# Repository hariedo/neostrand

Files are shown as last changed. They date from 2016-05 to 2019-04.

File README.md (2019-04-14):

# neostrand
NeoPixel + Arduino + Vocaloid Hairband Strand Project

On YouTube:  https://youtu.be/9ahXiw0cFx8

This is a nice multi-discipline maker project combining:

* some 3D-printed parts for a hairband and a light controller case
* some Arduino Pro Mini boards, perfboard assembly style,
* some code that goes in the Arduino Atmel 328, and
* some very long strands of NeoPixel (WS2812B) RGB LEDs.

The goal is a hairband that can be worn to a Vocaloid event;
the Vocaloids are Japanese animated characters with synthesized
vocal tracks and visuals.  The lights on the hairband match the
colors and rhythm that the wearer chooses to select at any time.

Note that Vocaloid(tm) is a trademark of Yamaha Corporation, and
this project has no proprietary content nor connection with Yamaha.

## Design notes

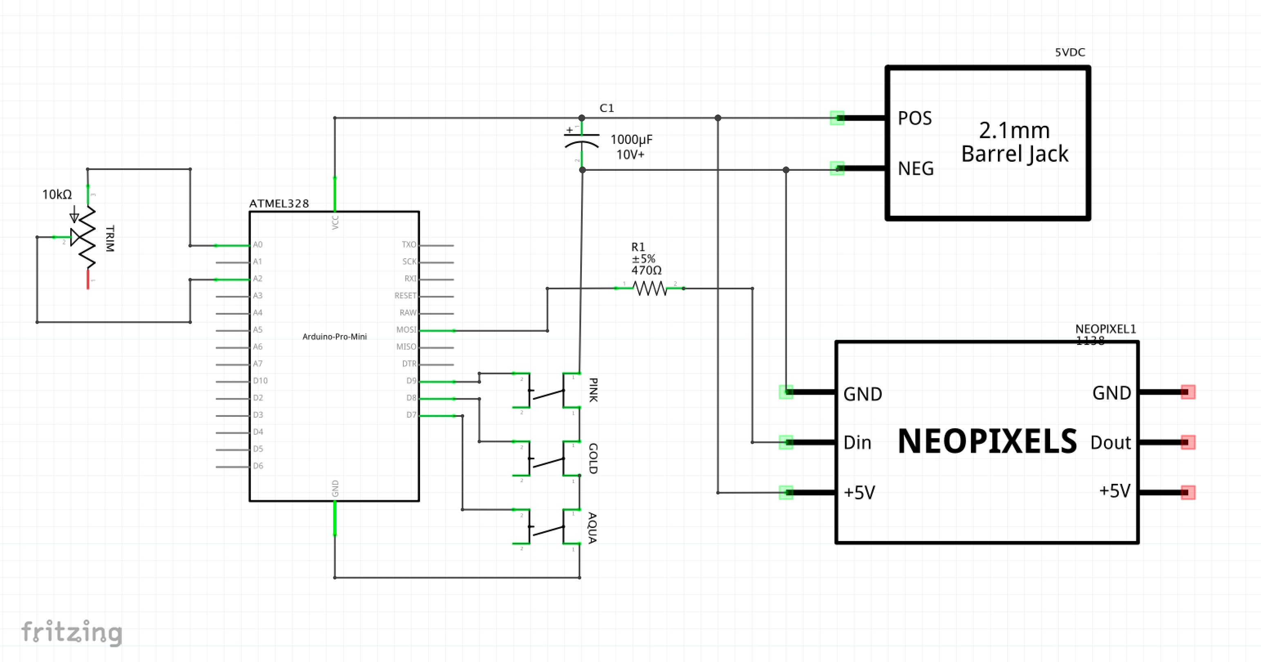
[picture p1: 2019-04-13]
fritz/NeoStrand_schematic.png

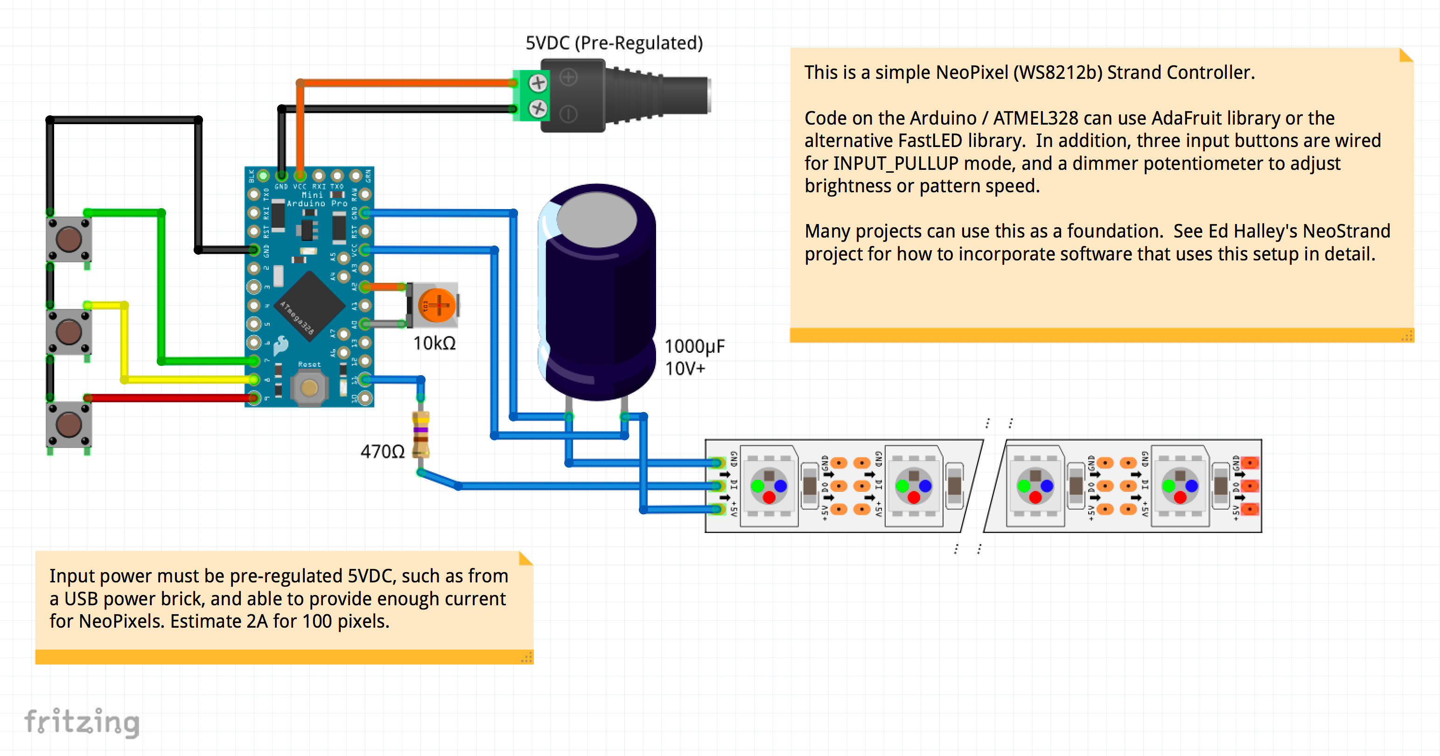
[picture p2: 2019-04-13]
fritz/NeoStrand_simple.png

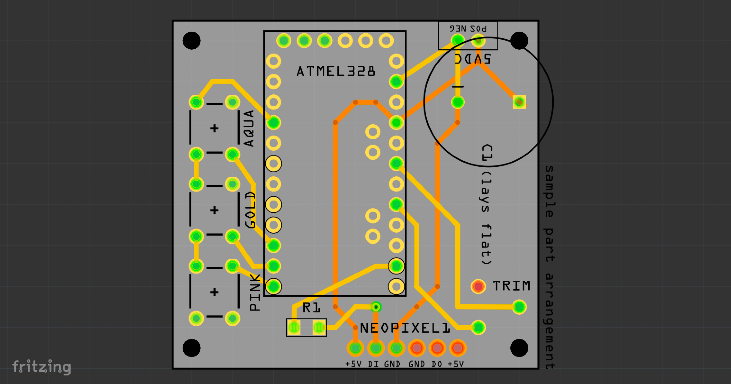
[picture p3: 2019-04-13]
fritz/NeoStrand_pcb.png

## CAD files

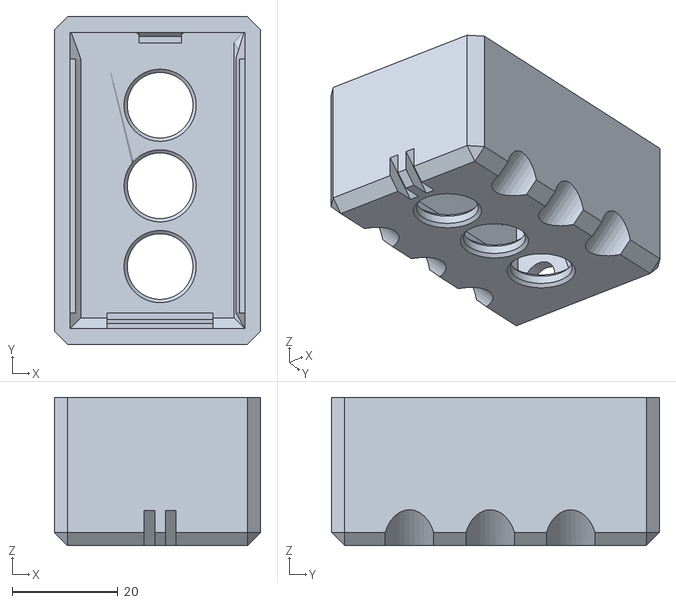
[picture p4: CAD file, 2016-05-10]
stl/neostrand-button-box.stl
39.0 x 62.0 x 28.0

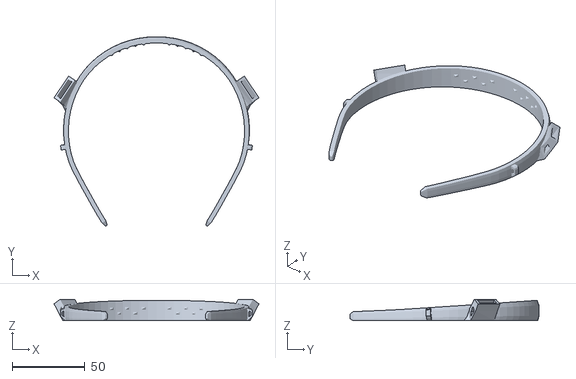
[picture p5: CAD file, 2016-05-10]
stl/hairband-with-strand-mounts.stl
140.5 x 129.8 x 14.7

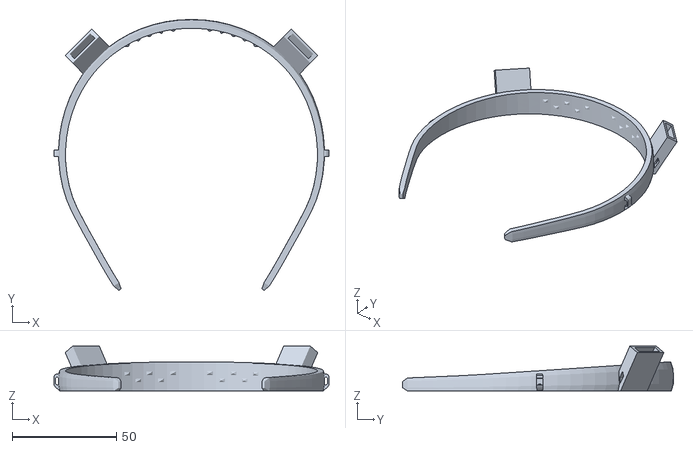
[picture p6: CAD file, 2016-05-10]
stl/hairband-with-teeth.stl
131.7 x 129.8 x 21.5

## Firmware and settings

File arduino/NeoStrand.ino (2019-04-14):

// Vocaloid NeoPixel Strand Controller
// Copyright (c) by Ed Halley and Jaime Halley
//
// On YouTube:  https://youtu.be/9ahXiw0cFx8
// On GitHub:   https://github.com/hariedo/neostrand
//
// Vocaloid NeoPixel Strand Controller is licensed under a
// Creative Commons Attribution-ShareAlike 4.0 International License.
// 
// Vocaloid(tm) is a trademark of Yamaha Corporation. This project has no
// proprietary content from, nor infers any relationship with Yamaha.
//
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

#include "Generic.h"

//
// Circuit Concept for the Vocaloid NeoPixel Strand Controller:
//
//                                  |< accessory >| == |< character color >|
// Battery ==== Arduino =========== |A|A|A|A|A|A|A| == |C|C|C|C|C|C|C|...|C|
//              ^B ^B ^Buttons
//
// A battery is attached to a small box with an Arduino and three momentary
// buttons.  A longer cord stretches from the small box to a hairpiece that
// has one or two NeoPixel(tm) WS2812-style shift register RGB LED devices
// in series.  The wearer can select the modes and special effects by
// pressing combinations of buttons on the control box.  The first N pixels
// are dedicated as an accent/accessory color, while the remaining pixels are
// intended to display the main character signature color.  These pixels are
// typically arranged on the wearer's head, such as from a hairband.  There
// are convenient rings of NeoPixels that work well as the hair accessory.
// If no hair accessory component is attached, then set the ACCESSORY_LENGTH
// to 0 and no pixels for accent colors will be reserved.  Set the
// CHARACTER_LENGTH to the length of the main NeoPixel device; the macro
// STRAND_LENGTH is the sum total of these.
// 
// To celebrate the main Vocaloid star, Hatsune Miku, the wearer should have
// two complete (independent) hardware units, with a 12- or 16-LED ring for
// the accessory and a 1-meter high density 144-pixel strand for each of two
// long ponytails (twintails).
// 
// A large-capacity USB charger that can supply over 2A per port is
// sufficient if the LEDs are not driven at full power.  A dimming
// potentiometer option is included to adjust the brightness.  The pixels
// will jitter and show inaccurate colors if there is not enough current
// available for the brightness setting.  If not using a USB charging device
// and your supply is more than 5V, you MUST INCLUDE a suitable 5V DC
// REGULATOR or you will damage the NeoPixels.  An Arduino's DC regulator is
// typically not able to drive multiple amps of current.  Best practice is
// to have an electrolytic capacitor damp the changes in current demand,
// wired in parallel across the power supply to the NeoPixel strip.
// Suggested value is 1000uF rated for 10V or higher.
//

//----------------------------------------------------------------------------

//
// Define all our program constants.  These are chosen based on the wiring
// and timing, and never change without recompiling and re-loading the
// Arduino code.
//

// We connect a NeoPixel strand to one data pin on the Arduino.  We have to
// declare how many LEDs (total) are in the overall NeoPixel strand.  We
// can reserve a certain portion of the top of the strand for an accessory
// color, or use 0 for no accessory.
//
// Best practice is to have a moderate resistor in series between the
// STRAND_PIN and the NeoPixel strand input.  Suggested resistor value is
// 470ohms.
//
#include "NeoStrand.h"
#define STRAND_PIN 11
#define ACCESSORY_LENGTH 16
#define CHARACTER_LENGTH 144
#define STRAND_LENGTH (ACCESSORY_LENGTH+CHARACTER_LENGTH)
NeoStrand strand = NeoStrand(STRAND_LENGTH, STRAND_PIN);

// We connect three normally-open momentary buttons (with helpfully
// colored caps) to three data pins on the Arduino.  The opposite pin of
// each button is grounded.  The combination of these buttons will be
// monitored.  So if the user pushes one button, such as the LUKA/pink
// button, then LUKA's mode will be selected; if the user pushes a combo
// like LUKA+TWIN, then a different mode is selected instead.  In this way,
// we have a maximum of 8 combos (all off, three ways to push one button,
// three ways to push two buttons together, and one combo if pushing all
// three buttons together. 
//
#define LUKA_BUTTON 9
#define TWIN_BUTTON 8
#define MIKU_BUTTON 7

// If a special debugging button is wired up, we can react to it.  This can
// be useful on the breadboard stage, but left out of the final circuit
// buildup.
//
#define DEBUG_BUTTON 4

// These are timing constants that we use to control the speed of various
// parts of the sketch.  Each loop cycle is roughly 1~3ms, depending on the
// length of the strand.
//
#define SCROLL_CYCLES 2
#define RAINBOW_CYCLES 2
#define CONFIRMATION_CYCLES 12
#define HISTORY_CYCLES 250
#define HOLD_MODE_CYCLES 800

// We want to keep some historical data on recent button pushes, to detect
// special patterns of presses like hold, double-tap, etc.  In this way,
// we can greatly increase the power of the limited user interface.
//
#define HISTORY_LENGTH 6
unsigned long history_millis = 0;
unsigned long history_time[HISTORY_LENGTH];
int history_vector[HISTORY_LENGTH];

// This list of names corresponds to all of the major Vocaloid modes that
// we want to support.  Since we have three buttons, we have a maximum of
// eight MAJOR modes that are easy to select.  The mode numbers are also
// used as the "input vector," representing the user's button combination
// pressed at any given instant.
//
enum
{
  NOBODY=0,
  MIKU=1,   // green alone gives miku aquamarine (and dark red accent)
  TWIN=2,   // yellow alone for the blonde twins (and white accent)
  KAITO=3,  // green+yellow gives bold blue (and baby blue accent)
  LUKA=4,   // red button alone gives pink (and teal accent)
  HAKU=5,   // green+red gives white (and pastel purple accent)
  MEIKO=6,  // yellow+red gives bold red (and brown accent)
  EVERYONE, // all three buttons
};

// The current major Vocaloid character mode.
int mode = NOBODY;

// For each vocaloid mode we support, we have a signature color based on
// a Vocaloid character's hair or costume color.  These colors can be
// any RGB color, 0~255 Red + 0~255 Green + 0~255 Blue.  Brighter is
// better; we can always dim the colors separately.
//
uint32_t VocaloidColors[] =
{
  strand.Color(0, 0, 0),       // NOBODY
  strand.Color(40, 255, 130),  // MIKU AQUAMARINE HAIR
  strand.Color(200, 200, 30),  // TWINS RIN/LEN BLONDE
  strand.Color(10, 10, 255),   // KAITO BLUE
  strand.Color(240, 70, 70),   // LUKA PINK
  strand.Color(180, 180, 180), // IA/HAKU SILVERY WHITE OUTFIT
  strand.Color(255, 10, 10),   // MEIKO RED OUTFIT
  strand.Color(200, 0, 200),   // RAINBOW [updated all the time]
};

// For each vocaloid mode we support, we have a secondary color based on the
// same Vocaloid(tm) character's costume accent color.
//
uint32_t AccessoryColors[] =
{
  strand.Color(0, 0, 0),       // NOBODY
  strand.Color(80, 10, 10),    // MIKU RED/BLACK HAIR RINGS
  strand.Color(200, 200, 200), // TWINS RIN/LEN WHITE HAIR BOW
  strand.Color(70, 70, 140),   // KAITO BABY BLUE SCARF
  strand.Color(40, 200, 250),  // LUKA TEAL HEADPHONES
  strand.Color(180, 100, 180), // IA/HAKU PASTEL MAGENTA HAIR
  strand.Color(30, 20, 10),    // MEIKO BROWN HAIR
  strand.Color(200, 0, 200),   // RAINBOW [updated all the time]
};

// This list of names corresponds to all of the minor effect modes that we
// want to support.  We can have as many as we want here, but we have to
// have some kind of way of tapping, pushing, double-tapping, or holding
// the buttons to achieve the selection, so keep it simple.
//
enum
{
  NONE=0,     // no change
  SOLID,      // default effect for a single tap
  PULSING,    // tap for at least 3 beats, it will try to match rhythm
  SPARKLING,  // double-tap the buttons quickly and stop
  SHUTDOWN,   // hold the buttons for 3 seconds
};
unsigned long pulsingPeriod = 1000;

// NeoPixel brightness ranges from 0~255.
// Full brightness is energy-inefficient and blindingly bright.  We also
// want to reserve some extra brightness for special effects. So here, we
// define the typical brightness level. Wiring a trim potentiometer
// between the DIMMER_PIN and VCC will let you further adjust the overall
// effect.  Suggested value is 10kohm.
//
#define RESTING_BRIGHTNESS 130
#define DIMMER_PIN (A0)
int dimmer = 255;

//----------------------------------------------------------------------------

// The "setup" function is run one time, shortly after power is provided.
// In this function, we can perform whatever things we think are necessary
// before the main loop begins.
//
void setup()
{
  Serial.begin(115200);

  // Buttons are input devices.
  // For these buttons, we will use the Arduino internal pullup-resistor
  // mechanism, which means that they will read as HIGH when not pushed,
  // and LOW when pushed.  Wire each button to their respective input pin
  // and to the common circuit ground.
  //
  pinMode(LUKA_BUTTON, INPUT_PULLUP);
  pinMode(TWIN_BUTTON, INPUT_PULLUP);
  pinMode(MIKU_BUTTON, INPUT_PULLUP);
  pinMode(DEBUG_BUTTON, INPUT_PULLUP);
  //pinMode(DIMMER_PIN, INPUT);
  
  // LEDs are output devices.
  // Set up the NeoStrand device which will initialize the pin mode and
  // all of the pixels on the strand are cleared to black/off.
  //
  strand.begin();
  strand.show();

  // When we first power on, we wait for user input before full effect.
  //
  mode = performWait(MIKU);
  mode = performBoot(mode);
}

//----------------------------------------------------------------------------

int performWait(int target)
{
  // Wipe the slate clean first.
  strand.wipeWithColor(0);
  strand.show();

  // Ensure we're not already being manipulated with buttons.
  while (NOBODY != getConfirmedInputVector())
    delay(1);

  // Indicate power is available on the first pixel.
  // Otherwise you might forget you need to start pushing buttons.
  //
  uint32_t color;
  int decay = 0;
  int delta = +1;
  while (NOBODY == getConfirmedInputVector())
  {
    // The EVERYONE mode's special rainbow color is updated all the time.
    updateRainbow();
    color = VocaloidColors[target];
    
    strand.setPixelColor(ACCESSORY_LENGTH, NeoStrand::Bright(color, decay));
    strand.show();
    delay(1);

    // breathing pattern
    decay += delta;
    if (decay > 255 || decay < 0)
    {
      decay = constrain(decay, 0, 255);
      delta = -delta;
    }
  }

  while (1)
  {
    // The EVERYONE mode's special rainbow color is updated all the time.
    updateRainbow();
    color = VocaloidColors[target];

    strand.setPixelColor(ACCESSORY_LENGTH, color);
    strand.show();
    delay(1);

    int vector = getConfirmedInputVector();
    if (vector == NOBODY)
      break;
    target = vector;
  }

  // We have poor entropy at power startup, but it is much better
  // if we can allow for some kind of user interaction before seeding.
  // So we seed the number generator after this first button push.
  // Luckily, quality random numbers aren't too important here.
  //
  randomSeed(getCheapEntropy());

  return target;
}

int performBoot(int target)
{
  int first = target;
  int duration = 400;

  // Slowly build up the distribution of sparkles.
  //
  int decay = 0;
  for (int i = 0; i < duration; i++)
  {
    // The EVERYONE mode's special rainbow color is updated all the time.
    updateRainbow();

    uint32_t color = VocaloidColors[target];
    
    int chance = random(duration);
    if (chance < i)
    {
      decay = 255;
      if (random(1000) < 50 && i < duration*7/8)
        target = random(8);
      else
        target = first;
    }
    else
    {
      decay /= 3;
      decay = constrain(decay, 0, 255);
      color = NeoStrand::Bright(color, decay);
    }

    dimmer = updateDimmer();
    if (dimmer < 255)
      color = NeoStrand::Bright(color, dimmer);

    strand.scrollForward();
    strand.setPixelColor(0, color);
    strand.show();

    // Ramp in the speed of the cascade.
    //
    int speed = map(i, 0, duration, 20, 1);
    delay(speed);
  }
  target = first;

  // Fade down into resting brightness level.
  //
  duration = 300;
  for (int i = 0; i < duration+STRAND_LENGTH; i++)
  {
    uint32_t color = VocaloidColors[target];
    int decay = map(i, 0, duration, 255, RESTING_BRIGHTNESS);
    decay = constrain(decay, RESTING_BRIGHTNESS, 255);
    color = NeoStrand::Bright(color, decay);
    if (dimmer < 255)
      color = NeoStrand::Bright(color, dimmer);
    strand.scrollForward();
    strand.setPixelColor(0, color);
    strand.show();
    delay(1);
  }

  // Past user input is irrelevant.
  //
  clearHistory();

  return target;
}

//----------------------------------------------------------------------------

// The "loop" function is run repeatedly, until power is removed or the
// device is reset.  In this function, we can perform whatever things we
// want to have happen endlessly.
//
void loop()
{
  unsigned long now = millis();

  // Check if debugging has been requested.
  updateDebug();

  // The EVERYONE mode's special rainbow color is updated all the time.
  updateRainbow();

  // Update our overall brightness factor from a trim knob.
  dimmer = updateDimmer();

  // Check all our inputs and get one number representing all the buttons
  // together.  The "confirmed input" function includes some special logic
  // to ensure the user's intended input, since two or three buttons are
  // hard to press or release at exactly the same instant.
  //
  int currentVector = getConfirmedInputVector();

  // Any positive change in confirmed vector instantly changes the overall
  // "mode" of our system to a new Vocaloid character, and feeds the new
  // mode's color into the top of the strand.
  //
  static int effect = SOLID;
  static int lastMode = EVERYONE;
  if (currentVector != NOBODY)
  {
    mode = currentVector;
    if (mode != lastMode)
      effect = SOLID;
  }

  // Monitor the history of this input vector.  Certain timing patterns can
  // be detected to select a sub-mode special effect.
  //
  int command = detectEffectCommand(currentVector);
  if (command != NONE)
    effect = command;

  // Special combo of holding all buttons means to go dark instead.
  //
  if (effect == SHUTDOWN)
  {
    strand.wipeWithColor(0, 1);
    mode = performWait(mode);
    mode = performBoot(mode);
    clearHistory();
    lastMode = NOBODY;
    effect = SOLID;
  }

  updateStrand(mode, effect);

  // Tell the strand device we've finally decided what we want to display.
  strand.show();
  while (now == millis())
    ;

  lastMode = mode;
}

//----------------------------------------------------------------------------

// Sometimes it can be tough to figure out why a feature is not working,
// since you can't just look inside a variable while the chip is running
// the program.  So this function offers a way to pause and report any
// useful information back to the host computer.
//
// If the button is pushed, print anything you want, then wait for the
// button to be released.  You don't even need an actual button.  Just
// short the DEBUG_BUTTON pin to any ground pin.
//
void updateDebug()
{
  if (isButtonPressed(DEBUG_BUTTON))
  {
    // Print whatever you want back to the host computer.
    Serial.print("---\n");
    Serial.print("history_vector = {");
    for (int i = 0; i < HISTORY_LENGTH; i++)
    {
      if (i > 0) Serial.print(", ");
      Serial.print(history_vector[i]);
    }
    Serial.print("};\n");
    Serial.print("history_time = {");
    for (int i = 0; i < HISTORY_LENGTH; i++)
    {
      if (i > 0) Serial.print(", ");
      Serial.print(history_time[i]);
    }
    Serial.print("};\n");

    Serial.print("dimmer = ");
    Serial.print(dimmer);
    Serial.print(";\n");

    // Wait for the debug button to be released, so as not to spam the
    // terminal with too much data.
    //
    delay(100);
    while (isButtonPressed(DEBUG_BUTTON))
      ;
  }
}

//----------------------------------------------------------------------------

// Read the potentiometer option and scale the results to our NeoPixel
// dimmer range.  We don't allow the potentiometer to dim all the way down
// to zero, because it makes it pretty confusing to debug the circuit with
// no lights.  We also don't want it to go too dark because the colors get
// a bit inaccurate if scaled too low.
//
int updateDimmer()
{
    int trimmer = analogRead(DIMMER_PIN - A0);
    dimmer = map(trimmer, 0, 1023, 100, 255);
    return dimmer;
}

// Wipe the history arrays of all the past user input behavior.
//
void clearHistory()
{
  memset(history_time, 0, sizeof(history_time));
  memset(history_vector, 0, sizeof(history_vector));
  history_millis = millis();
}

// Check out the history arrays to see if the user has executed a triple-
// tap of the same button vector combo.  If so, set up the PULSING effect.
//
int detectTripleTap()
{
#if HISTORY_LENGTH < 6
#error Need more HISTORY_LENGTH to support detectTripleTap()
#endif

  // The vector history arrays need to match this pattern:
  //
  //                   < most recent                 least recent >
  // history_vector:   [ NOBODY, x, NOBODY,     x, NOBODY, x, ... ]
  // history_time:     [      ?, y,      w,     y,      w, ?, ... ]
  //
  // The 'y+w' times have to be approximately equal (within HISTORY_CYCLES).
  // The pulse rate becomes defined as the average of the last two 'y+w'
  // timespans.
  //
  if (history_vector[0] == NOBODY &&
      history_vector[2] == NOBODY &&
      history_vector[4] == NOBODY)
  {
    if (history_vector[1] == NOBODY)
      return NONE;

    if (history_vector[1] == history_vector[3] &&
        history_vector[3] == history_vector[5])
    {
      unsigned long period0 = history_time[1]+history_time[2];
      unsigned long period1 = history_time[3]+history_time[4];
      if (period1 > period0 && period1-period0 > HISTORY_CYCLES)
        return NONE;
      if (period0 > period1 && period0-period1 > HISTORY_CYCLES)
        return NONE;

      pulsingPeriod = (period0+period1)/2;
      return PULSING;
    }
  }

  return NONE;
}

// Check out the history arrays to see if the user has executed a double-
// tap of the same button vector combo.  If so, set up the SPARKLING
// effect.
//
int detectDoubleTap()
{
#if HISTORY_LENGTH < 4
#error Need more HISTORY_LENGTH to support detectDoubleTap()
#endif

  // The vector history arrays need to match this pattern:
  //
  //                   < most recent           least recent >
  // history_vector:   [ NOBODY, x, NOBODY, x, ... ]
  // history_time:     [      ?, ?,  short, ?, ... ]
  //
  if (history_vector[0] == NOBODY && history_vector[2] == NOBODY)
  {
    if (history_vector[1] == NOBODY)
      return NONE;

    if (history_vector[1] == history_vector[3])
    {
      if (history_time[2] > HISTORY_CYCLES*2)
        return NONE;

      return SPARKLING;
    }
  }

  return NONE;
}

// Check out the history arrays to see if the user has executed a long-
// tap of the same button vector combo.  If so, set up the SHUTDOWN
// effect.
//
int detectLongTap()
{
#if HISTORY_LENGTH < 2
#error Need more HISTORY_LENGTH to support detectLongTap()
#endif

  // The vector history arrays need to match this pattern:
  //
  //                   < most recent   least recent >
  // history_vector:   [ x,    ... ]
  // history_time:     [ long, ... ]
  //
  if (history_vector[0] != NOBODY)
  {
    if (history_time[0] > HOLD_MODE_CYCLES)
      return SHUTDOWN;
  }

  return NONE;
}

// This routine records the recent history of user actions, and then
// checks if any of the special effect commands can be detected in the
// history data.
//
int detectEffectCommand(int vector)
{
  unsigned long now = millis();

  // If the vector of input buttons has changed at all, we record
  // this change in the history.  The last HISTORY_LENGTH vector
  // states are kept.
  //
  if (vector != history_vector[0])
  {
    // push the new vector onto the stack
    memmove(&history_vector[1], &history_vector[0],
            sizeof(*history_vector)*(HISTORY_LENGTH-1));
    memmove(&history_time[1], &history_time[0],
            sizeof(*history_time)*(HISTORY_LENGTH-1));
    history_vector[0] = vector;
    history_millis = now;
  }

  // The latest entry in the history is always counting upward from the
  // last change.  Thus, when the next change is pressed onto the history,
  // it represents the length of time there was no change.
  //
  int since = (now - history_millis);
  history_time[0] = since;

  int effect = NONE;
  if (effect == NONE)
    effect = detectTripleTap();
  if (effect == NONE)
    effect = detectDoubleTap();
  if (effect == NONE)
    effect = detectLongTap();

  return effect;
}

//----------------------------------------------------------------------------
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

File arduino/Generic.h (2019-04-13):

// Generic but useful Arduino helper functions and macros.
//
// Generic.h
// Copyright (c) by Ed Halley and Jaime Halley
//
// Generic.h is licensed under a
// Creative Commons Attribution-ShareAlike 4.0 International License.
// 
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

#ifndef __GENERIC_H__
#define __GENERIC_H__

//----------------------------------------------------------------------------

// The sizeof operator gives the byte size of the whole array.
// This macro gives the number of elements in an array.
//
#define countof(array)  ( sizeof(array) / sizeof(*(array)) )

//----------------------------------------------------------------------------

// Entropy is a measure of disorder or chaos.
//
// In cryptography or random numbers, you want to mix in any available
// unpredictable numbers so that the calculations will be highly
// unpredictable.
//
// An Arduino has very poor support for strong entropy, and it would be
// time-consuming to gather it anyway.  This function collects what is
// readily available with minimal delay:  all of the device ports.
//
// Call this function when you need to seed a PRNG but not whenever you
// need a random number from the PRNG.  For example, shuffle the deck once
// (to seed) but draw many cards from the deck before shuffling again.
//
// Enhancements to get stronger entropy would be to attach a sensor that
// reads from a real-world chaotic input (humidity, noise, vibrations,
// camera pixel data, etc.).  This routine would then naturally combine
// that data with other cheap entropy data.  Some Atmel controllers have
// an internal temperature sensor which could have a little bit of entropy
// as the device warms from a cold startup.  Additionally, store some seed
// state into EEPROM:  read a previously recorded value from EEPROM,
// combine it with new entropy, seed the PRNG from this, and store a new
// value back into EEPROM for the next power-up.  Don't write EEPROM
// excessively as it will wear out over time.
//
inline unsigned long getCheapEntropy()
{
  static unsigned long entropy = 0xDEADBEEF;
  static unsigned char shift = 0x0F;

  // The current low-order bits of Arduino runtime in micros() is great...
  // if this function is called after a human-based interaction.  If only
  // called during the Arduino setup() function or called on a very
  // regular basis, it's going to be horribly predictable.
  //
  entropy ^= micros() << shift;

  // The analog input pins will always have a little bit of repeatability
  // error in them.  This is almost zero if hardwired to ground or VCC,
  // or configured as an output pin.  The repeatability jitter is pretty
  // weak if attached to a real input device.  If a pin is left
  // unconnected there is a little more room for unpredictable values
  // coming in.  Note that small Arduino Pro Mini style boards often have
  // no connection points (or inconvenient ones) attached to the analog
  // pins A4 and A5.
  //
  entropy ^= analogRead(0) << shift;
  entropy ^= analogRead(1) << (shift+3);
  entropy ^= analogRead(2) << (shift+6);
  entropy ^= analogRead(3) << (shift+9);
  entropy ^= analogRead(4) << (shift+12);
  entropy ^= analogRead(5) << (shift+15);

  // The digital input pins can be read 8 at a time.  These are even less
  // likely to be useful as entropy sources unless the user is actively
  // pushing buttons or there is some kind of data transmission going on
  // across the SDI or serial pins at the time.
  //
  entropy ^= PORTB << shift;
  entropy ^= PORTC << (shift+8);
  entropy ^= PORTD << (shift+16);

  // On successive calls to this routine, we alter how we mix our inputs
  // into the current entropy pool.  This helps ensure that calling us
  // multiple times does not defeat the entropy gained.  However, it's
  // still not a good idea to call this routine constantly, such as in
  // every main loop().
  //
  shift = entropy & 0x0F;

  return entropy;
}

//----------------------------------------------------------------------------

// Retrieve a value INPUT, INPUT_PULLUP, or OUTPUT, from the current
// pin setting.
//
inline int getPinMode(uint8_t pin)
{
  uint8_t bit = digitalPinToBitMask(pin);
  uint8_t port = digitalPinToPort(pin);

  if (port == NOT_A_PIN)
    return -1;

  volatile uint8_t* reg = portModeRegister(port);
  volatile uint8_t* out = portOutputRegister(port);

  if ((~(*reg) & bit) == bit) // INPUT OR PULLUP
  {
    if ((~(*out) & bit) == bit)
      return INPUT;
    else
      return INPUT_PULLUP;
  }

  return OUTPUT;
}

// Turn the INPUT or INPUT_PULLUP digital input into a useful logical
// false=unpressed / true=pressed return value.
//
inline bool isButtonPressed(uint8_t pin)
{
  int mode = getPinMode(pin);
  if (mode == OUTPUT || mode < 0)
    return false;
  bool pressed = digitalRead(pin);
  if (mode == INPUT_PULLUP)
    pressed = !pressed;
  return pressed;
}

//----------------------------------------------------------------------------

// Count the number of 1-bits in the given long integer.
//
inline int countBits(unsigned long i)
{
  i = ((i & 0xAAAAAAAAL) >>  1) + (i & 0x55555555L);
  i = ((i & 0xCCCCCCCCL) >>  2) + (i & 0x33333333L);
  i = ((i & 0xF0F0F0F0L) >>  4) + (i & 0x0F0F0F0FL);
  i = ((i & 0xFF00FF00L) >>  8) + (i & 0x00FF00FFL);
  i = ((i & 0xFFFF0000L) >> 16) + (i & 0x0000FFFFL);
  return (int)i;
}

// Determine if the given long integer is a power of two.
// (Alternative:  countBits(i) == 1.)
//
inline bool isPowerOfTwo(long i)
{
  return i && !(i & (i-1));
}

// Reverse the bits of a long integer.
//
inline unsigned long reverseBits(unsigned long i)
{
  unsigned long r = i;
  int s = sizeof(i)*8 - 1;
  for (i >>= 1; i; i >>= 1)
  {   
    r <<= 1;
	r |= i & 1;
	s--;
  }
  r <<= s;
  return r;
}

//----------------------------------------------------------------------------

#endif // __GENERIC_H__

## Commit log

2016-05-10 Initial push with sketch and STL files.
    [hairband-with-strand-mounts.stl, hairband-with-teeth.stl, neostrand-button-box.stl]
2019-04-13 Added Fritzing files to demonstrate the basic circuit
    [NeoStrand.fzz]

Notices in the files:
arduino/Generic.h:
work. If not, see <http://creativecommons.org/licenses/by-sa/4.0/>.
